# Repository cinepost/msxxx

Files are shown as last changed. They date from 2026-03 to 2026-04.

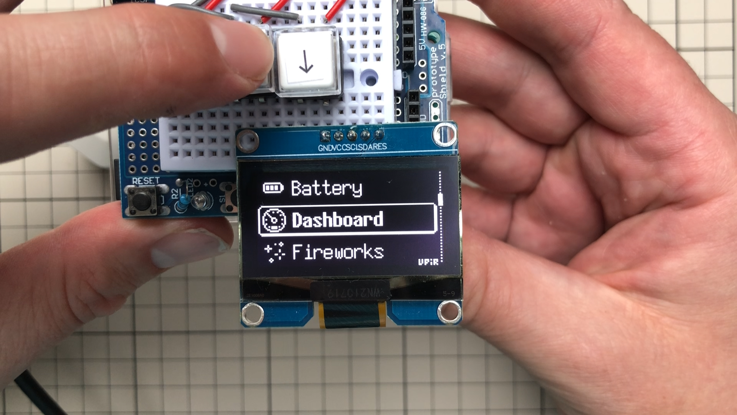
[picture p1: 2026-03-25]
refs/oled_128_64/211014461-b9f0f969-bd4d-4982-b2ad-dad3fd539f9a.png

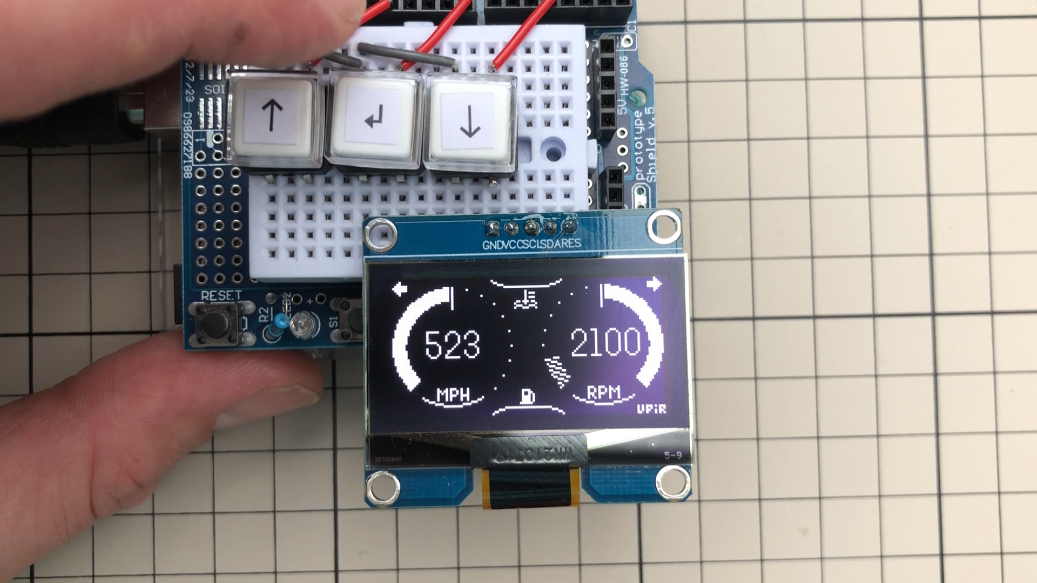
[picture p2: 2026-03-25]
refs/oled_128_64/211014477-58950704-ad14-4b65-a108-19dc7b484e64.png

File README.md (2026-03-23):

# MSX2+ FPGA Implementation

An advanced FPGA-based recreation of the MSX2+ architecture, optimized for high-fidelity video and audio output. This project leverages the Altera Cyclone I (EP1C12) and an external MCU for system management.

## ⚙️ System Architecture
- **Core Logic**: Implemented on an **Altera Cyclone I (12K LE)**, capturing the full MSX2+ specification.
- **System Controller**: An **RPi Pico (RP2040)** handles initial FPGA configuration (bitstream loading) and real-time system settings.
- **Video Path**: Features a dedicated **ADV7123 Triple DAC** for high-precision signal generation, bypassing standard FPGA-pin PWM limitations.
- **Audio Path**: **Sigma-Delta audio output** for superior sound clarity and reduced noise floor.

## 📺 Video Features
Supporting a wide array of legacy and modern connections via dedicated driver chips:
- **RGB / VGA**: High-quality analog output via the ADV7123.
- **S-Video & CVBS**: Dedicated encoding hardware for authentic retro display compatibility.
- **Improved Signal Integrity**: Specialized circuitry to ensure stable sync and color reproduction across all outputs.

## 🔊 High-Fidelity Audio
This implementation moves beyond standard FPGA PWM audio, featuring a dedicated high-end analog stage:
- **Primary DAC**: **Cirrus Logic CS4398** (120dB Dynamic Range, 24-bit/192kHz capable) for superior Delta-Sigma D/A conversion.
- **Output Stage**: **NE5532 Op-Amp** configured for low-noise buffering and active filtering.
- **Audio Quality**: Crystal-clear MSX sound synthesis with significantly reduced harmonic distortion and a professional-grade noise floor.

## 🛠️ Hardware Requirements
*   FPGA: Altera Cyclone I (EP1C12 version).
*   MCU: Raspberry Pi Pico or compatible RP2040 board.
*   Video DAC: Analog Devices ADV7123.
*   Supporting discrete components for video filtering and audio amplification.

## 🚀 Getting Started
1. **Flash the MCU**: Load the RP2040 firmware to manage the FPGA bridge.
2. **FPGA Bitstream**: Place the compiled `.rbf` files on the designated storage (Internal Flash).
3. **Power On**: The Pico will configure the Cyclone I and initialize the MSX environment.

## 🔧 Future Improvements
- [ ] Additional sound chip synthesis (SCC+, OPLL).
- [ ] Enhanced firmware interface for the RP2040 OSD.

## 📄 License
This project is licensed under the [WTFPL License](LICENSE).

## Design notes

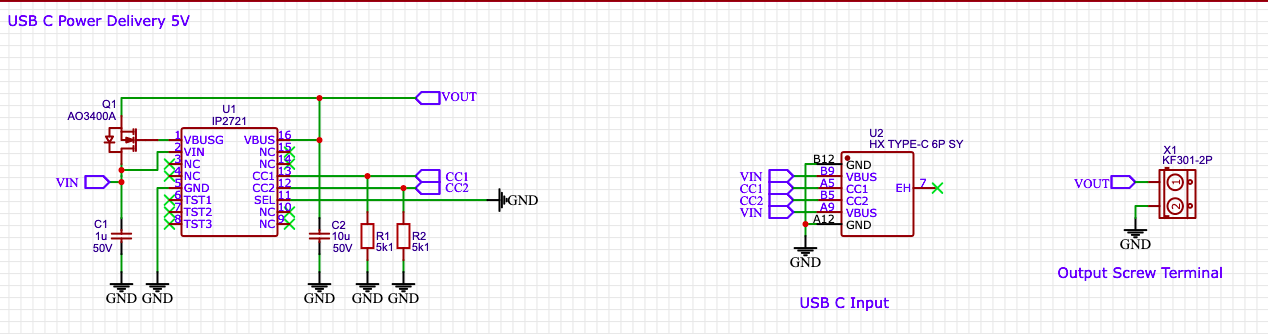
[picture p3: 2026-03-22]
hardware/images/usb-power-delivery-5v-only-board-by-beginner-v0-pt00tz8in68d1.png

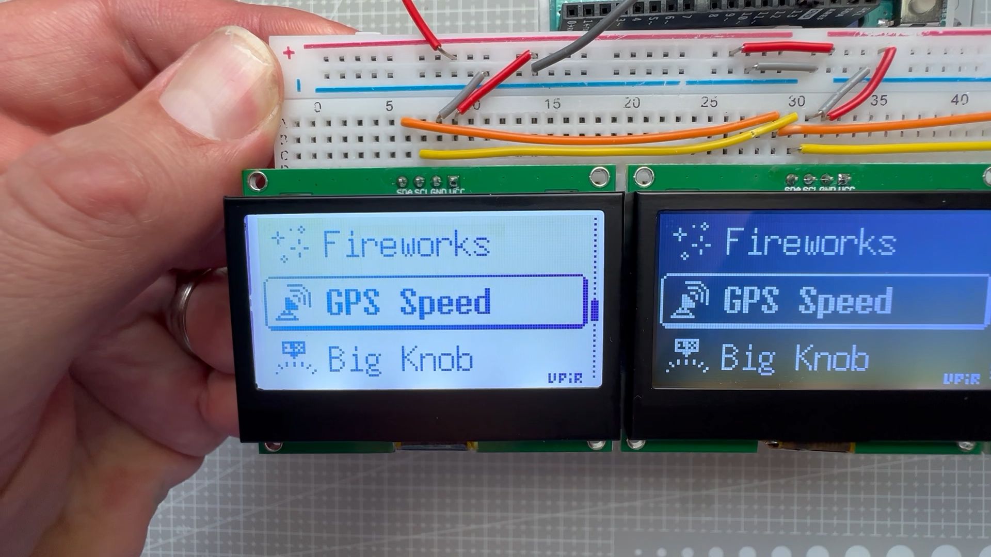
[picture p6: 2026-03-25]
refs/oled_128_64/224031252-fd56c354-3740-4be0-8f59-a4a1d75e0430.jpg

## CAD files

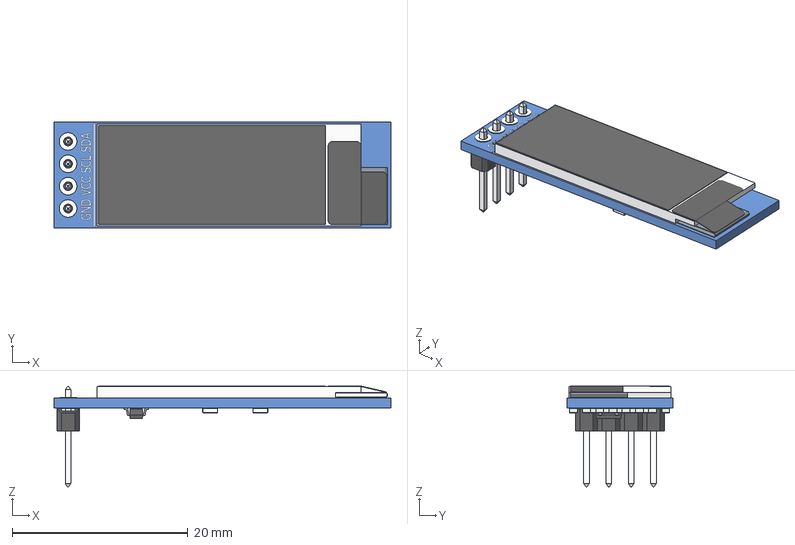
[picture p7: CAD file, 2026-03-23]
hardware/3d_models/OLED_0.91_128x32.stp
38.3 x 12.1 x 11.5 mm
OLED_0.91_128x32
Pin Header 4 x 1 TH 2.54mm Pitch
RESC-0603 x 13
2SD0601A

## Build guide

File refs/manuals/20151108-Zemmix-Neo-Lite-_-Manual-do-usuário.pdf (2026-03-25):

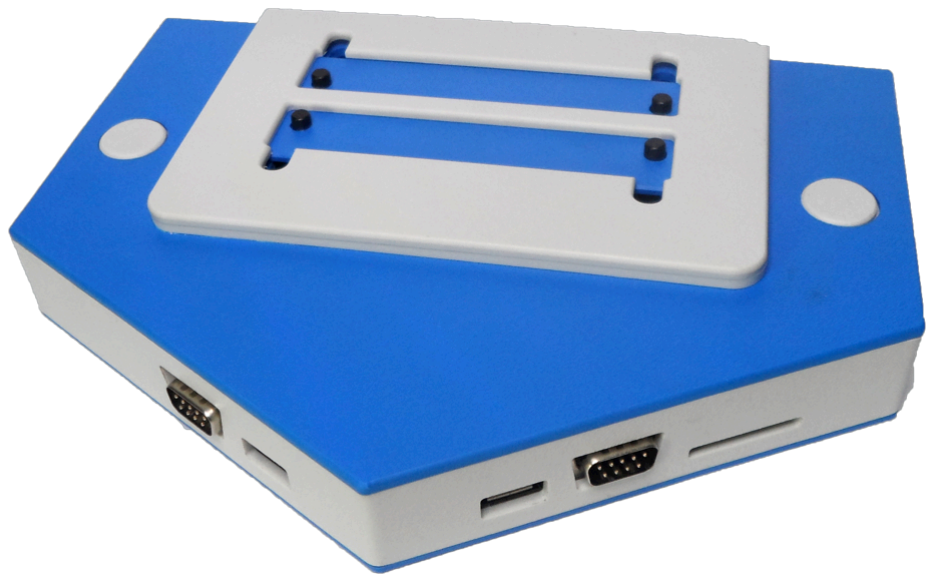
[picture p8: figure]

# Zemmix Neo Lite BR Edition Manual do Usuário

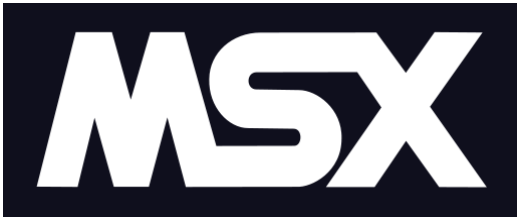
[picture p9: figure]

A obra Zemmix Neo Lite BR Edition - Manual do Usuário de Bruno Nazareth está licenciado com uma Licença Creative Commons -Atribuição-NãoComercial 4.0 Internacional. Baseado no trabalho disponível em mailto: brnazareth em gmail ponto com.

## Índice

## 1. O que é o MSX (definição da Wikipedia)

MSX é o nome de uma arquitetura padrão para computadores pessoais, lançada pela Microsoft em 16 de junho de 1983 e concebido por Kazuhiki Nishi, vice-presidente da Microsoft Japão e diretor da ASCII Corporation. Diz-se que a Microsoft liderou o projeto como uma tentativa de criar um padrão unificado para os fabricantes de hardware. Apesar do envolvimento da Microsoft, computadores baseados no MSX raramente são vistos nos Estados Unidos, mas foram populares em países como Japão, Oriente Médio, Brasil, União Soviética, Holanda, Espanha e menor volume em diversos países europeus. É difícil estimar quantos computadores MSX foram vendidos mundialmente, mas eventualmente 5 milhões de unidades foram vendidas apenas no Japão.

## 2. Sobre o Zemmix Neo

O Zemmix Neo é um hardware baseado na placa e código fonte do One Chip MSX (OCM). Basicamente, foram implementadas todas as funcionalidades do OCM e acrescentado um gerador de scanlines. Possui ainda suporte a teclados USB que emulem o padrão PS2.

## 3. Especificações

- Compatível com MSX2+
- Turbo de 8MHz
- 4 Megabytes de Mapper e 1 Megabyte de ESE-MegaRAM
- Saída VGA 15/31KHz
- Saídas de Vídeo Composto, S-Video
- Cartão SD (até 2GB em FAT16)
- Teclado PS/2 e USB
- 2 Slots para cartuchos
- Áudio Estéreo
- FM
- 1MB ESE-RAM SCC+
- Entrada para Cassete

## 4. Diagrama físico

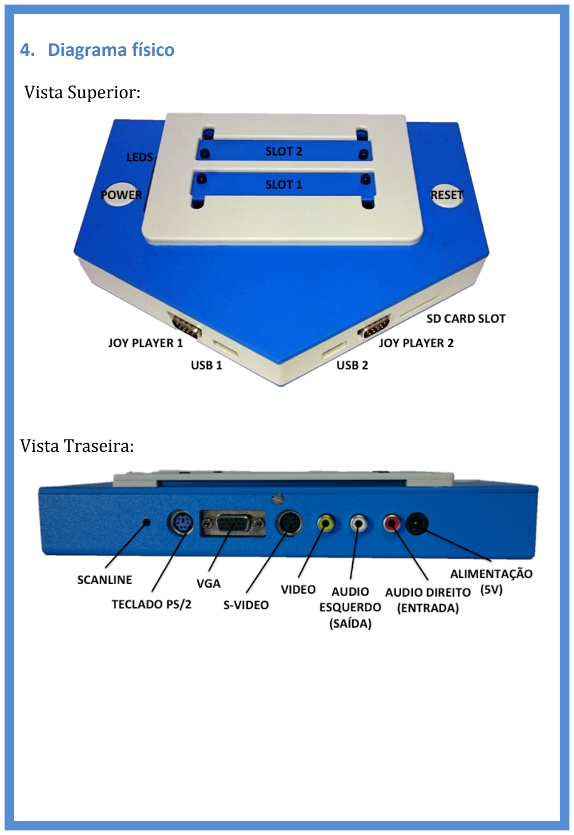
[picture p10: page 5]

Vista Superior:

Vista Traseira:

## 5. Como Ligar Seu Zemmix Neo

Antes de ligar seu Zemmix Neo, efetue as seguintes conexões:
1) Alimentação: a fonte deve ser de 5 volts e 2 ampéres. O polo positivo é o pino central.
2) Video: para melhor qualidade de imagem é recomendado utilizar a saída de video VGA. O Zemmix Neo, diferentemente de computadores MSX clássicos, suporta qualquer monitor equipados com este tipo de conector. Caso sua televisão não suporte essa entrada, prefira SVIDEO e por último o conector de VIDEO (amarelo).
3) Audio: conecte as saídas de audio direita e esquerda a uma caixa de som amplificada ou uma mesa/amplificador externo. Caso sua televisão não suporte audio stereo, utilize apenas o conector de saída de audio esquerdo (branco).
4) Teclado: a porta USB 2 suporta utilização de teclados que emulem o protocolo PS/2. Teclados reconhecidos como HID (Human Interface Device) não são suportados. Teclados padrão PS/2 também podem ser utilizados no conector traseiro do Zemmix Neo.
5) Cartuchos ROM ou Cartão SD: Insira os cartuchos ROM ou o cartão SD nos slots.

ATENÇÃO: Remover qualquer conexão ou dispositivo de armazenamento com seu Zemmix Neo ligado pode danifica-lo. Desligue sempre o Zemmix Neo antes de fazer qualquer alteração.

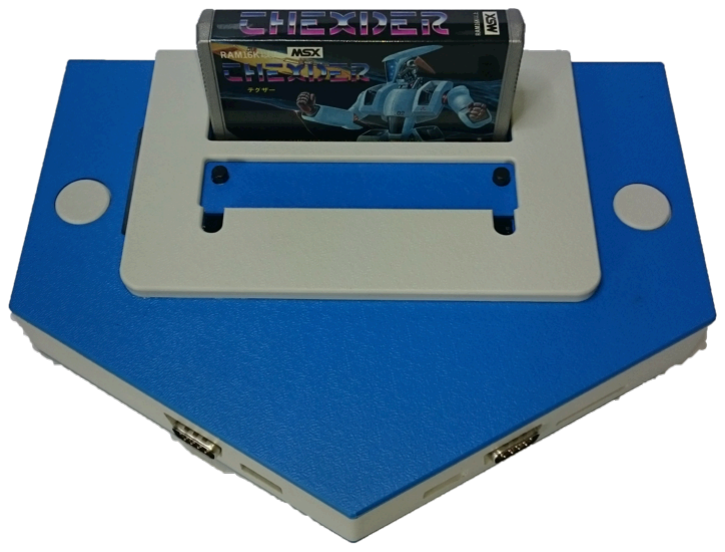
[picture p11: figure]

## 6. Configurações de Dip Switches

Switch | Função | Estado | Explicação
SW1 | Velocidade CPU | Desligado | Modo 3,58 MHz
| | Ligado | Velocidade personalizada (8,06MHz) - Modo TurboPANA é 5,37MHz - Turbo MegaSD é habilitado como padrão
SW2/SW3 | Saída de Vídeo | Desligado/Desligado | Modo Video Composto/S-Video (15KHz Interlaçado, 50/60Hz)
| | Desligado/Ligado | RGB-Audio Mono (15KHz, vídeo Interlaçado, 50/60Hz, SCART, Aúdio mono no conector VGA)
| | Ligado/Desligado | VGA brilho normal (31KHz progressivo, 60Hz somente)
| | Ligado/Ligado | VGA com scanlines (31KHz progressivo, 50/60Hz)
SW4 | Configuração Slot 1 | Desligado | Usar Slot 1 externo
| | Ligado | Modo ESE MegaSCC+ interna (1024KB) - Slot 1 externo desabilitado
SW5/SW6 | Configuração Slot 2 | Desligado/Desligado | Usar Slot 2 externo
| | Desligado/Ligado | Modo ESE MegaRAM interna [ASCII-8KB-BANK] (1024KB) - Slot 2 externo desabilitado
| | Ligado/Desligado | Modo ESE MegaSCC+ interna (1024KB) - Slot 2 externo desabilitado
| | Ligado/Ligado | Modo ESE MegaRAM interna [ASCII-16KB-BANK] (1024KB) - Slot 2 externo desabilitado
SW7 | Memory Mapper | Desligado | RAM interna de 2048KB
| | Ligado | RAM interna de 4096KB
SW8 | Cartão SD | Desligado | Desabilitado
| | Ligado | Ligado

Exemplo de dip switches (recomendada por padrão):
- Ligadas: 1, 2, 3 e 8
- Desligadas: 4, 5, 6, 7

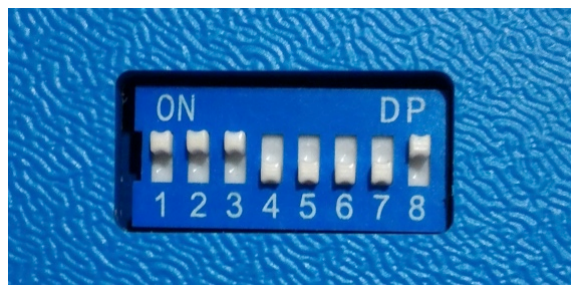
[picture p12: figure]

## 7. Atalhos de teclado

O Zemmix Neo suporta teclados PS/2 ou USB que emule comandos PS/2. Algumas teclas de um MSX tradicional foram mapeadas para serem adequadas aos teclados modernos. Existem também algumas teclas e combinações que podem ser utilizadas para alterar as configurações de hardware do Zemmix Neo:

Tecla ou Combinação | Função
END | Tecla STOP do MSX.
ALT | Tecla GRAPH do MSX.
WIN | Tecla SPACE do MSX.
F6 | Tecla GRAPH do MSX.
F7 | Tecla KANA do MSX.
F8 | Tecla SELECT do MSX.
F9 | Aumenta o volume do PSG.
SHIFT + F9 | Abaixa o volume do PSG.
F10 | Aumenta o volume do SCC.
SHIFT + F10 | Abaixa o volume do SCC.
F11 | Aumenta o volume do OPL.
SHIFT + F11 | Abaixa o volume do OPL.
PAGE UP | Aumenta o volume geral.
PAGE DOWN | Abaixa o volume geral.
F12 | Altera o clock da CPU entre 3 valores: 3,58MHz, 5,37MHz, ou Personalizado 8MHz.
PRINTSCREEN | Altera o tipo de saída de vídeo na sequencia: CVBS/S-Video, SCART, VGA 31KHz, VGA+ 31KHz.
SHIFT + PRINTSCREEN | Altera o tipo de saída de vídeo na sequencia: VGA+ 31KHz , VGA 31KHz, SCART, CVBS/S-Video.
SCROLL LOCK | Ativa ou desativa o modo Cassete.
SHIFT + F12 | Altera a configuração do SLOT 1: externo/SCC+.
SHIFT + SCROLL LOCK | Altera a configuração do SLOT 2: externo/ASCII8/SCC+/ASCII16.

## 8. Leds de Status

Os LEDs indicam algumas configurações atuais. Os LEDs Verdes são numerados de 1 a 8 no sentido de cima para baixo e o Vermelho é o 9. Durante os ajustes de volume os LEDs são usados para indicar o nível de volume, no estilo Bargraph. Após um tempo os LEDs voltam à indicar as configurações atuais:

Led | Status | Status
1 | Piscando | Atividade no Cartão SD ou memória Flash.
2 | Apagado Aceso | Memória Mapper a 2MB. Memoria Mapper a 4MB.
3/4 | Apagado/Apagado Apagado/Aceso Aceso/Apagado Aceso/Aceso | SLOT 2 Externo Ativo ESE-MegaRAM ASCII 8K Ativa ESE-MegaSCC+ Ativa ESE-MegaRAM ASCII 16K Ativa
5 | Apagado Aceso | SLOT 1 Externo Ativo ESE-SCC+ Ativa
6/7 | Apagado/Apagado Apagado/Aceso Aceso/Apagado Aceso/Aceso | Modo Vídeo Composto / S-Video Modo RGB-Audio(SCART) Modo VGA brilho normal Modo VGA com scanlines
8/9 | Apagado/Apagado Apagado/Aceso Aceso/Apagado | Clock de 3.58 MHz Clock de 5.37 MHz Clock Custom

No teclado os LEDs também são indicadores para alguns estados:
- LED Scroll Lock: modo cassete ativado;
- LED: Num Lock: modo Kana ativado.

## 9. Execução de Programas no Zemmix Neo

## 9.1.Como usar cartuchos ROM MSX

Os dois slots do Zemmix Neo podem ser utilizados para executar cartuchos ROM. Para ativar o slot 1 é necessário manter a dip switch 4 desligada. Para ativar o slot 2, desligue as dip switches 5 e 6.
Após alterar as configurações das dip switches, basta inserir o cartucho e ligar o Zemmix Neo.

ATENÇÃO: Não insira ou remova os cartuchos com o Zemmix Neo Ligado!

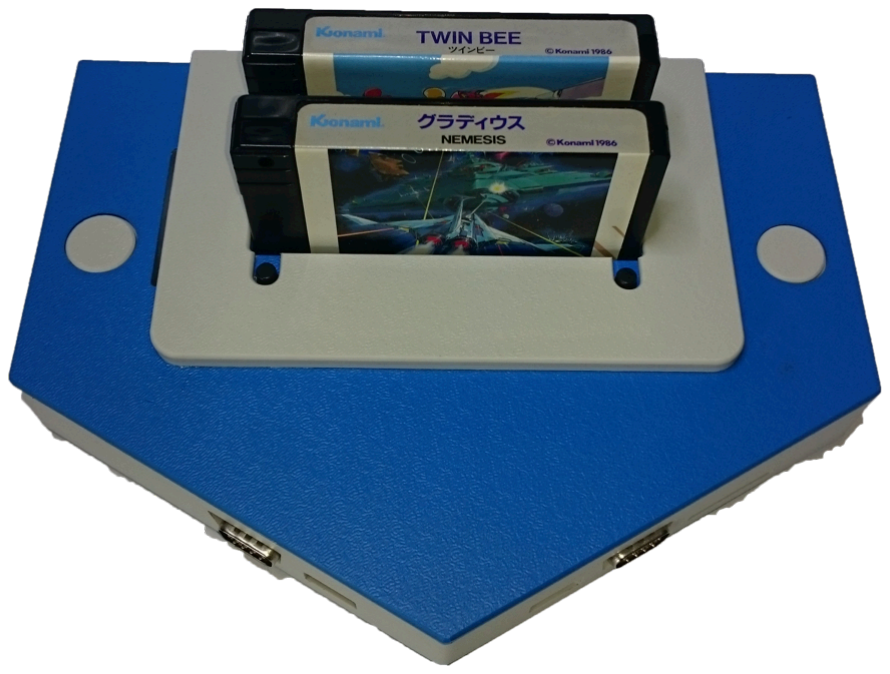
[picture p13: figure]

## 9.2.Uso de drive externo

Além de alterar as dip switches para habilitar os slots para Interface de drive externo, é necessário ainda desabilitar o leitor de cartões SD que pode interferir no funcionamento:

1. Desligue a dip switch 8. (Quando a dip switch 8 está ligada significa habilitar o cartão de leitor SD e pode gerar erros com o FDD)
2. Insira a interface de drive no slot - Pode ser utilizado qualquer slot. Certifique-se que está bem encaixado.
3. Ligar o Zemmix Neo

Caso tenha um disco inserido no drive, ele será lido. Caso contrário será exibida a tela de Disk BASIC.

## 9.3.Uso de gravador de dados

É possível ligar um gravador de fitas cassete ao Zemmix Neo:

1. Desligue a dip switch 8 para usar o gravador de dados.
2. Ligar o Zemmix Neo e apertar a tecla Scroll Lock uma vez.
3. Ligar o gravador no conector RCA VERMELHO. Esse conector é compartilhado como entrada e saída K7.
4. Inserir o comando adequado.

Após a exibição da tela de BASIC, entre com o comando CLOAD (Pode ser utilizado BLOAD, RUN de acordo com o manual de instruções da fita cassete). Não existe conexão “remote” no Zemmix Neo, portanto é requerido pressionar os botões play/stop/record no gravador manualmente.

## 9.4.Uso de cartão SD

É possível utilizar cartões SD como armazenamento de programas executáveis, arquivos ROM, arquivos DSK e etc. O Zemmix Neo aceita cartões de no máximo 2GB formatados apenas em FAT16.

ATENÇÃO: O Zemmix Neo não é compatível com cartões SDHC e não suporta cartões maiores que 2GB.

1. Certifique-se que o cartão utilizado é compatível com o Zemmix Neo.
2. Ligue a dip switch 8 com o Zemmix Neo desligado.
3. Insira o cartão SD no Zemmix Neo. Será escutado um clique quando o cartão estiver conectado corretamente.

4. Use o cartão SD como um dispositivo de armazenamento em massa.

Após a inicialização, será exibida a tela do Disk BASIC. Podem ser utilizados os comandos de BASIC para manipulação de arquivos (FILES, SAVE, LOAD, etc…) para controlar o cartão SD. Normalmente, o cartão SD é reconhecido como drive A. Caso exista uma interface de disco externa conectada, o cartão será reconhecido como drive C.

5. Uso do MSX-DOS2: Os arquivos MSXDOS2.SYS e COMMAND2.COM podem ser copiados para o cartão SD. É possível encontrar esses arquivos em repositórios na Internet.
6. Uso do ROMLOAD: Arquivos ROM podem ser executados através do comando romload <arquivo .rom>. Os arquivos ROM podem ser executados em conjunto com a emulação da SCC+ e MegaRAM controladas através das dip switches 4, 5 e 6.
7. Uso do MGLOCM: Arquivos ROM podem ser executados através do comando mglocm <arquivo .rom> com configuração automática dos periféricos internos.

Para remover o cartão SD, desligue o Zemmix Neo e pressione o cartão. Será ouvido um clique quando o cartão for ejetado.

ATENÇÃO: O LED 8 piscará quando o cartão SD estiver em uso. O cartão pode ser danificado se removido ou o Zemmix Neo com o cartão estiver em uso. Verifique se o cartão está em uso antes de remove-lo.

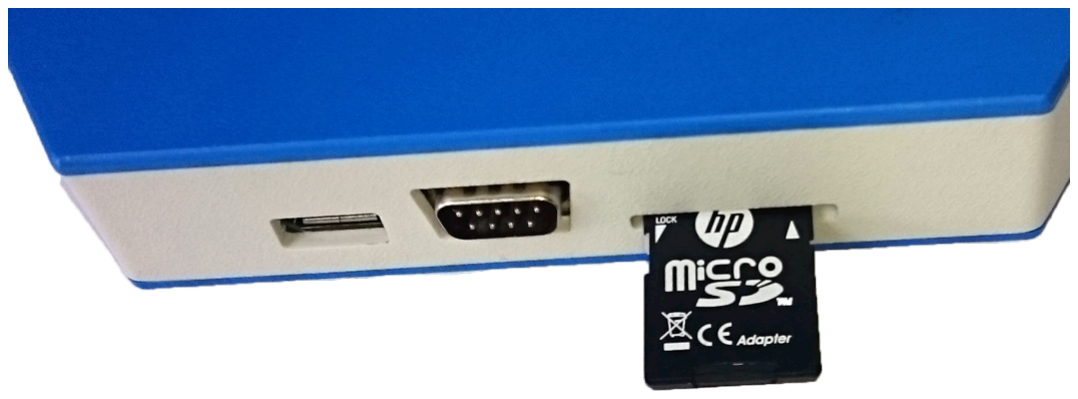
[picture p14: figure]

## 9.5.Execução de discos de jogos (Uso do ep.com)

### 1. Jogos multi-disco (Exemplo: YS 2)

Copie as imagens de disco YS21.DSK e YS22.DSK para o cartão SD (no mesmo diretório).

Execute o comando “ep YS2*.DSK /b /r” na linha de comando.

É possível alterar o disco com o atalho F7+Enter e depois pressione o número do disco (0 a 9).

### 2. Jogos de um disco como Age of Discovery (Jogos da Koei)

Acrescente as seguintes linhas ao Autoexec.bat:

set shell=b:\command.com
path b:\

Copie o arquivo Dai.dsk (imagem do Age of Discovery) e o reboot.com para o cartão SD.

Execute o comando “ep DAI.DSK a:” e execute “reboot.com” a partir do drive A.

É possível salvar status dos jogos em disco. Também pode utilizar uma PAC ou FM-PAC. Alguns jogos que verificam “S-RAM” não podem ser salvos na PAC ou FM-PAC.

ATENÇÃO: Este método de troca de discos não funciona para jogos do tipo “3 Kingdoms”.

### 3. Snatcher, SD-Snatcher ou Konami Game Collections

Ligue a dip switch 5, desligue a dip switch 6 (ESE-SCC+) no Zemmix Neo e execute o comando ep para o arquivo em questão.

## 9.6.Execução de jogos Megarom

1. Usar o romload.com para jogos megarom.
Execute o comando “romload ROM_NAME.rom /r /s” com a dip switch 5 ligada e a 6 desligada.

Se o arquivo ROM não for executado, é possível abrir o arquivo romload.lst para validar as opções do romload. O romload.com possui uma configuração interna para permitir a execução de Konami SCC, Konami4 (Metal Gear 1 e 2, Maze of Galious, etc…), ASCII (Bubble Bobble), ASC16K (Aleste).
2. Usar Ngload para carregar jogos megarom.
Altere as dip switches no Zemmix Neo para cada tipo de cartucho:
5 desligado, 6 ligado: ESE-ASCII 8K
5 ligado, 6 desligado: ESE-SCC+
5 ligado, 6 ligado: ESE-ASCII 16K

Execute o comando “ngload ROM_NAME /r”.

É necessário alterar a extensão do arquivo ROM. Por exemplo, Konami SCC deve ser alterado para SCK/SKN/ROM, Konami 4 alterado para KNM, ASC 8k alterado para 8K e ASC 16K alterado para 16K.
É necessário alterar a mapper megarom em conjunto com as dip switches do Zemmix Neo.

### 3. Jogos Koei 4M

Desligue a dip switch 5 e ligue a 6 (ESE-ASCII 8K).

Ao executar uma ROM Koei 4M será exibido na tela “S-RAM check”. É possível executar o jogo e salvar na PAC ou FM-PAC. Não funciona para todos os jogos da Koei.

### 4. MGLOCM

Outra opção é usar o utilitário MGLOCM.COM. Deixe as dip switches 4, 5 e 6 desligadas, execute o comando “mglocm ROMFILE.ROM” e o utilitário irá reconhecer o formato da ROM, configurar os slots de acordo com o necessário e executar o jogo.
ATENÇÃO: Ao executar o MGLOCM os slots externos podem ser desativados para a ativação dos periféricos internos, causando travamento se houver algum cartucho de armazenamento em massa sendo utilizado.

## 10.Solução de problemas

Verifique essas soluções caso encontre problemas.

Problema: O Zemmix Neo não liga.
- O cabo de força está ligado corretamente?
- A Fonte é compatível? O Zemmix Neo suporta alimentação de 5 volts com até 2 ampéres e polo positivo no centro. Apesar de funcionar, não é recomendado a alimentação pelas portas USB pois não existem proteções contra surtos de energia nessas entradas.

O Zemmix Neo está ligado mas não exibe nada na tela.
- Está ligado corretamente na TV? O conector de video no Zemmix Neo é igual ao da TV (amarelo).
- O conector/cabo não está com defeito?
- A lâmpada de status acende corretamente?
- Alguns monitores VGA não suportam a saída do Zemmix neo. Tente utilizar as saídas S-video ou A/V.
- Através das combinações das dip switches 2 e 3 é possível trocar os modos de exibição. Se a tela não exibir nada e não for detectado um problema de hardware, verifique as configurações das dip switches.

ATENÇÃO: Não utilize mais de uma saída de video simultaneamente. Isso pode danificar seu Zemmix Neo.

O teclado não funciona
- O teclado está conectado na porta PS/2 ou na porta USB da direita? O conector USB da esquerda não pode ser utilizado para teclado. A maioria dos teclados USB podem ser utilizados com o Zemmix Neo, mas alguns teclados não são compatíveis com a conexão PS/2. Tente um outro teclado.
- O Zemmix Neo utiliza algum teclado especial?
O Zemmix Neo utiliza o teclado padrão ABNT. Se forem pressionadas múltiplas teclas, algumas podem ser reconhecidas erroneamente.

O cartucho de ROM não funciona.
- O cartucho não está sujo? Limpe o cartucho e o slot se o cartucho não funcionar.
- Alguns cartuchos precisam ser iniciados com a tecla shift pressionada.

- Mesmo se for inserido o cartucho no Zemmix Neo com as configurações das dip switches corretas, pode ser exibida a tela do BASIC ou gráficos distorcidos. Pode ser por causa de sujeira no slot para cartuchos. É necessário proceder com a limpeza do slot.
Para limpar o slot, pode utilizar um cotonete embebido com um pouco de álcool isopropílico ou etanol. Espere secar antes de utilizar o slot.

Programa no disco não funciona
- O disco não está danificado?
- O Software no disco é compatível com MSX/MSX2/MSX2+? O Zemmix Neo é compatível com MSX2+, entretanto, não é possível garantir 100% de compatibilidade. Software de Turbo-r não é compatível.
- A leitura de discos pode ser afetada caso a cabeça de leitura esteja suja. É necessário utilizar um disco de limpeza para corrigir o problema.

Cartão SD não funciona
- A dip switch 8 está desligada? O Zemmix Neo pode ter sido enviado da “fábrica” com a dip switch desligada.
- O cartão está formatado com FAT16? Utilize este programa para formatar o cartão SD (o programa de formatação do Windows 7 pode causar alguns problemas).
http://panasonic.jp/support/audio/sd/download/sd_formatter.html

Joystick não funciona.
- O Joystick (joypad) é compatível com MSX? O conector é idêntico ao Sega Genesis/Mega Drive, mas não é compatível.

Não é possível escutar nada.
- A saída de áudio está ligada na TV? A entrada/saída de áudio também é utilizada com o gravador de dados. Se a SCC ou outros cartuchos de áudio estiverem em uso, ligue apenas o conector branco.

## 11.Links úteis

KdL Index!
Firmwares e Roms para o Zemmix Neo http://gnogni.altervista.org/

MSX.ORG Download Database/ROM Utilities
mglOCM
http://www.msx.org/downloads/utilities/rom

MSX Banzai!
MSX-DOS2, EP, FDLoad, ROMLOAD... http://msxbanzai.tni.nl/computers/ese3.html

Documentação do Projeto por Luis Fernando Zanoto
http://www.optotech.net.br/msx/zemmix_neo/

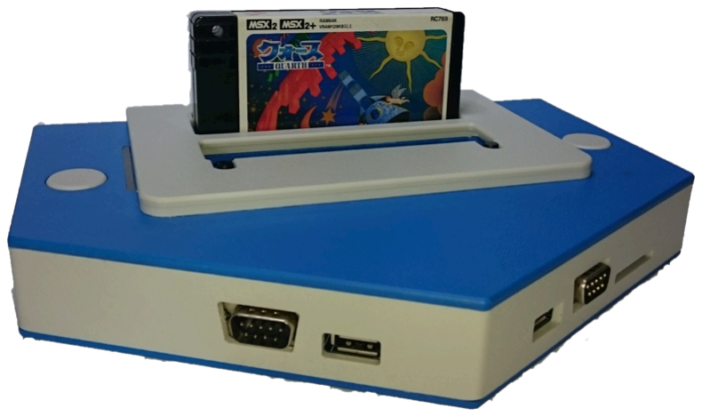
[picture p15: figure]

## Agradecimentos especiais para:

D4 Enterprise/ 1chipMSX
Retroteam Neo / Zemmix Neo

Projeto Zemmix Neo Lite BR Edition: Luis Fernando Luca
Luciano Sturaro
Fabio Belavenuto

Tradução Manual em Português: Bruno Nazareth

Imagens:
Rudolph Gutlich

E toda comunidade MSX que apoiou o projeto.

Novembro de 2015

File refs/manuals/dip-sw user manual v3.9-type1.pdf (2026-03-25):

# DIP-SW User Manual

## for 1chipMSX, Zemmix Neo, SX-1 and related (Cyclone I series)

## OCM-PLD Pack v3.9 by KdL

DIP-SW | FUNCTION | STATUS | DESCRIPTION
| | OFF | Standard mode 3.58MHz
| 1 | CPU Clock | ON | Custom Speed mode 4.10MHz to 8.06MHz (10.74MHz on system bus) • Press [F12] key to change clock type (3.58MHz >> 5.37MHz >> Custom Speed) • The external clock is set on [Sync to CPU] by default • [Turbo Pana] is 5.37MHz like the original specification • A special hybrid clock [Turbo MegaSD] is enabled by default
| | | OFF / OFF | Composite / S-Video • 15kHz, 50Hz+60Hz, interlaced video signal
| 2 / 3 | Video Output | OFF / ON | RGB w/ Audio Out (a mono signal inside the video cable) • 15kHz, 50Hz+60Hz, interlaced video signal, requires a VGA to SCART cable
| | | ON / OFF | VGA Mode for LED TV or LED Display • Progressive video signal 31kHz / 50Hz+60Hz with the ability to set the pixel ratio 1:1 at 60Hz
| | | ON / ON | VGA+ Mode for CRT Monitor (legacy output) (hardware scanlines on Zemmix Neo) • Progressive video signal 31kHz / 50Hz+60Hz / SETSMART -D0 must be executed to force 60Hz
| | | OFF | External Slot-1 • Advised like default
| 4 | Cartridge Slot-1 | ON | Internal ESE-MegaSCC+ 1024kB (shared w/ the 2nd half of ESE-MegaSCC+ Slot-2) • External Slot-1 is disabled • Memo: the CMT toggle is [Scroll Lock] key (disabled by default)
| | | OFF / OFF | External Slot-2 • Advised like default
| 5 / 6 | Cartridge Slot-2 | OFF / ON | Internal ESE-MegaRAM ASCII-8K 1024kB • External Slot-2 is disabled
| | | ON / OFF | Internal ESE-MegaSCC+ 2048kB • External Slot-2 is disabled
| | | ON / ON | Internal ESE-MegaRAM ASCII-16K 2048kB • External Slot-2 is disabled
| 7 | Internal Mapper | OFF | Internal 2048kB RAM • Advised like default
| | | ON | Internal 4096kB RAM
| | | OFF | Disabled
| 8 | Internal MegaSD | ON | Enabled • Advised like default

## KdL Index! < https://gnogni.altervista.org >

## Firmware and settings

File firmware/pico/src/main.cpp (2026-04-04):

#include <stdio.h>
#include "pico/stdlib.h"
#include "pico/multicore.h"
#include "pico/bit_ops.h"
#include "hardware/sync.h"
#include "hardware/spi.h"

#include "mcu_config.h"
#include "storage.h"
#include "i2c_expander.h"

// Pin Definitions
#define PIN_NCONFIG   16  // Output to FPGA
#define PIN_NSTATUS   17  // Input from FPGA
#define PIN_DCLK      18  // SPI0 SCK Clock (Set to 0 during reset)
#define PIN_CONF_DONE 20  // Input from FPGA
#define PIN_DATA0     19  // SPI0 TX
#define PIN_CS        21  //
#define SPI_PORT      spi0

#define PIN_LED       PICO_DEFAULT_LED_PIN

#define PIN_BTN_1     10  // OSD Button 1
#define PIN_BTN_2     11  // OSD Button 2
#define PIN_BTN_3     12  // OSD Button 3
#define PIN_BTN_4     13  // OSD Button 4

#define I2C_SDA_PIN   4
#define I2C_SCL_PIN   5
#include "ssd1306/ssd1306_i2c.h"     // OLED

//#define ENCODER_A      2
//#define ENCODER_B      3
//#define ENCODER_BTN    6
#if defined(ENCODER_A) && defined(ENCODER_B) && defined(ENCODER_BTN)
#define ENCODER_ENABLED 1
#else
#define ENCODER_ENABLED 0
#endif

#define MAX_FILES 16
#define MAX_FILENAME_LEN 32

// Mutlicore
// Shared data structure
struct {
    uint32_t    some_value;
    mutex_t     data_mutex;
} shared_state;

// --- State Management ---
// Define GPIOs for the 4 buttons
const uint BUTTON_PINS[] = {PIN_BTN_1, PIN_BTN_2, PIN_BTN_3, PIN_BTN_4};
uint8_t pico_buttons_state = 0;

// Virtual dip switches
uint8_t pico_dip_switches = 0b11001100;

// Core .rbf files
char file_list[MAX_FILES][MAX_FILENAME_LEN];  // Store filenames
int selected_index = 0;
int total_rbf_files = 0;

void init_buttons() {
    for (int i = 0; i < 4; i++) {
        gpio_init(BUTTON_PINS[i]);
        gpio_set_dir(BUTTON_PINS[i], GPIO_IN);
        gpio_pull_up(BUTTON_PINS[i]); // Enable internal pull-up
    }
}

uint8_t read_dip_state() {
    uint8_t state = 0;
    for (int i = 0; i < 4; i++) {
        // Logical NOT (!) because pull-up means 0 = Pressed
        if (!gpio_get(BUTTON_PINS[i])) {
            state |= (1 << i);
        }
    }
    return state; // Returns a value from 0-15
}

// Helper to check if string ends with a specific suffix
bool has_extension(const char *name, const char *ext) {
    size_t nl = strlen(name);
    size_t el = strlen(ext);
    return nl >= el && strcasecmp(name + nl - el, ext) == 0;
}

void populate_file_list() {
    lfs_dir_t d;
    lfs_dir_open(&lfs, &d, "/");
    struct lfs_info info;
    while (lfs_dir_read(&lfs, &d, &info) > 0 && total_rbf_files < MAX_FILES) {
        if (info.type == LFS_TYPE_REG) { // Regular file
            if (has_extension(info.name, ".rbf")) {
                strcpy(file_list[total_rbf_files++], info.name);
            }
        }
    }
    lfs_dir_close(&lfs, &d);
}

bool reset_fpga_sequence() {
    // 1. Ensure DCLK is low before starting
    gpio_put(PIN_DCLK, 0);

    // 2. Drive nCONFIG low to begin the reset
    gpio_put(PIN_NCONFIG, 0);

    // 3. Hold nCONFIG low (Cyclone I requires minimum 40us)
    // We use 100us to be safe and ensure the FPGA sees the pulse.
    sleep_us(100);

    // 4. Release nCONFIG (Drive High)
    gpio_put(PIN_NCONFIG, 1);

    // 5. Wait for the FPGA to finish clearing its memory
    // The FPGA signals it is ready when nSTATUS goes back to HIGH.
    uint32_t timeout = 5000; // 50ms timeout
    while (gpio_get(PIN_NSTATUS) == 0) {
        sleep_us(10);
        if (--timeout == 0) {
            // Error: FPGA is stuck in reset or nSTATUS is pulled low by hardware error
            return false; 
        }
    }

    // 6. Final Check
    // CONF_DONE must be LOW at this point because the FPGA is empty.
    if (gpio_get(PIN_CONF_DONE) == 1) {
        return false; // Error: FPGA didn't clear correctly
    }

    return true; // FPGA is ready for bitstream data
}

static inline uint8_t reverse_uint8(uint8_t b) {
    // __rev reverses 32 bits. If input is 0x01 (00...0001), 
    // it becomes 0x80000000. Shift right by 24 to get 0x80.
    return (uint8_t)(__rev(b) >> 24);
}

bool load_selected_fpga_core(const char* filename) {
    lfs_file_t f;
    int err = lfs_file_open(&lfs, &f, filename, LFS_O_RDONLY);
    if (err) { 
        printf("Error opening core file: %s\n", filename);
        return false;
    }
    
    // 1. Reset FPGA (Same as previous SPI logic)
    if(!reset_fpga_sequence()) {
        drawString(0, 0, "FPGA INIT ERROR!");
        return false;
    }

    // 2. Stream from Flash to FPGA
    uint8_t buffer[256];
    int read_bytes;
    while ((read_bytes = lfs_file_read(&lfs, &f, buffer, 256)) > 0) {
        // Bit-reverse here if files aren't pre-processed
        for(int i=0; i<read_bytes; i++) {
            buffer[i] = reverse_uint8(buffer[i]) >> 24;
        }
        spi_write_blocking(spi0, buffer, read_bytes);
    }
    
    lfs_file_close(&lfs, &f);
    
    // 3. Check Success
    if (gpio_get(PIN_CONF_DONE)) {
        drawString(0, 0, "SUCCESS!");
    }
    return true;
}

void init_hardware() {
    // Initialize Standard I/O (USB Serial for debugging)
    stdio_init_all();

    // Initialize PICO on-board LED
    gpio_init(PIN_LED); gpio_set_dir(PIN_LED, GPIO_OUT);

    // Initialize FPGA Control Pins
    gpio_init(PIN_NCONFIG); gpio_set_dir(PIN_NCONFIG, GPIO_OUT);
    gpio_put(PIN_NCONFIG, 1); // Default High

    gpio_init(PIN_NSTATUS); gpio_set_dir(PIN_NSTATUS, GPIO_IN);
    gpio_pull_up(PIN_NSTATUS); // FPGA usually has pull-ups, but let's be safe

    gpio_init(PIN_CONF_DONE); gpio_set_dir(PIN_CONF_DONE, GPIO_IN);
    gpio_pull_up(PIN_CONF_DONE);

    // Initialize High-Speed SPI (for FPGA Bitstream)
    // 20MHz is a safe speed for Cyclone EP1C12
    spi_init(spi0, 20 * 1000 * 1000);
    gpio_set_function(PIN_DCLK, GPIO_FUNC_SPI);
    gpio_set_function(PIN_DATA0, GPIO_FUNC_SPI);

    // Initialize I2C (for SSD1306 OLED)
    i2c_init(i2c0, I2C_CLOCK * 1000);
    gpio_set_function(I2C_SDA_PIN, GPIO_FUNC_I2C);
    gpio_set_function(I2C_SCL_PIN, GPIO_FUNC_I2C);
    gpio_pull_up(I2C_SDA_PIN);
    gpio_pull_up(I2C_SCL_PIN);
    initSSD1306();
    invertDisplay(true);
    updateDisplay();

    // Initalize I2C  at 100kHz (expander, rtc)
    i2c_init(i2c1, 100 * 1000);
    i2cExpanderInit(i2c1, 0x20);

    // Initialize Rotary Encoder Pins
#if ENCODER_ENABLED
    gpio_init(ENCODER_A);
    gpio_set_dir(ENCODER_A, GPIO_IN);
    gpio_pull_up(ENCODER_A);

    gpio_init(ENCODER_B);
    gpio_set_dir(ENCODER_B, GPIO_IN);
    gpio_pull_up(ENCODER_B);

    gpio_init(ENCODER_BTN);
    gpio_set_dir(ENCODER_BTN, GPIO_IN);
    gpio_pull_up(ENCODER_BTN);
#endif // ENCODER_ENABLED
}

static inline int read_buttons_state() {
    return 0;
}

static inline bool button_pressed() {
    return false;
}

// --- CORE 1: UI PROCESS ---
void core1_entry() {
    // Initialize UI/Display here (e.g., LVGL init)
    
    while (1) {
        // Read buttons state
        uint8_t data;
        i2cExpanderRead(data);

        uint32_t current_val;
        
        // Safely read shared data from Core 0
        mutex_enter_blocking(&shared_state.data_mutex);
        current_val = shared_state.some_value;
        mutex_exit(&shared_state.data_mutex);

        // Update UI elements with current_val
        // lv_timer_handler(); // Example for LVGL
        sleep_ms(16); // ~60fps target

        gpio_put(PIN_LED, 1);
        sleep_ms(500);
        gpio_put(PIN_LED, 0);
        sleep_ms(500);

        // Set expander leds
        uint8_t outputs = 0x00;
        i2cExpanderWrite(outputs); 
    }
}

int main() {
    // Init I2C for OLED, SPI for FPGA, and LittleFS
    init_hardware();

    // Launch UI on Core 1
    multicore_reset_core1();    
    multicore_launch_core1(core1_entry);

    mount_littlefs();
    init_buttons();

    mutex_init(&shared_state.data_mutex);

    while (true) {    

        // Display Menu
        clearDisplay();
        drawString(0, 0, "Select Core:");
        drawString(0, 20, file_list[selected_index]);
        updateDisplay();

        pico_buttons_state = read_buttons_state();
        printf("Buttons state: 0x%01X\n", pico_buttons_state);

        // If Button Pressed
        if (button_pressed()) {
            clearDisplay();
            drawString(0, 10, "Loading...");
            updateDisplay();
            if(load_selected_fpga_core(file_list[selected_index])) {
                // After config, switch pins 2 & 3 to SPI mode
                spi_init(spi0, 1000000);
                gpio_set_function(PIN_DCLK, GPIO_FUNC_SPI);
                gpio_set_function(PIN_DATA0, GPIO_FUNC_SPI);
                
                uint8_t fpga_readback = 0;

                while(true) {
                    gpio_put(PIN_CS, 0);
                    spi_write_read_blocking(spi0, &pico_dip_switches, &fpga_readback, 1);
                    gpio_put(PIN_CS, 1);
                    
                    printf("FPGA sent back: 0x%02X\n", fpga_readback);
                    sleep_ms(500);
                }
            } else {
                // TODO: handle configuration error
            }

            break;
        }

        // Perform logic: read sensors, calculate state, etc.
        uint32_t some_reading = (uint32_t)(get_absolute_time() / 1000);

        // Safely update shared data for the UI
        mutex_enter_blocking(&shared_state.data_mutex);
        shared_state.some_value = some_reading;
        mutex_exit(&shared_state.data_mutex);

        sleep_ms(100);
    }
}

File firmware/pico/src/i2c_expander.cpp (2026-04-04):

#include <stdlib.h>

#include "i2c_expander.h"

I2CExpanderConfig g_exp_i2c_conf;

void i2cExpanderInit(i2c_inst_t* port, uint8_t addr) {
    g_exp_i2c_conf.port = port;
    g_exp_i2c_conf.addr = addr;
    gpio_set_function(4, GPIO_FUNC_I2C);
    gpio_set_function(5, GPIO_FUNC_I2C);
    gpio_pull_up(4);
    gpio_pull_up(5);

    // Configuration: Pins 0-3 as INPUTS, Pins 4-7 as OUTPUTS
    // Binary: 0000 1111 -> 0x0F
    i2cExpanderWrite(0x0F, EXP_I2C_IODIR);
    
    // Enable Internal Pull-ups for pins 0-3 (Buttons)
    i2cExpanderWrite(0x0F, EXP_I2C_GPPU);
}

void i2cExpanderWrite(uint8_t val, uint8_t reg) {
    uint8_t buf[] = {reg, val};
    i2c_write_blocking(g_exp_i2c_conf.port, g_exp_i2c_conf.addr, buf, 2, false);
}

void i2cExpanderRead(uint8_t& data) {
    static uint8_t reg = EXP_I2C_GPIO;
    i2c_write_blocking(g_exp_i2c_conf.port, g_exp_i2c_conf.addr, &reg, 1, true);
    i2c_read_blocking(g_exp_i2c_conf.port, g_exp_i2c_conf.addr, &data, 1, false);
}

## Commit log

2026-03-23 pico led and buttons, virtual leds
    [OLED_0.91_128x32.stp, msxxx.kicad_sch]
2026-03-23 pico test firmware
    [msxxx.kicad_sch]
2026-03-26 i2c expander
